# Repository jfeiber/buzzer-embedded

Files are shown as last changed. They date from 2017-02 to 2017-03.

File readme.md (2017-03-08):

# Buzzer-Embedded

The embedded code portion of the Buzzer project. For the web app portion/main README see: https://github.com/jfeiber/buzzer. 

## Architecture

The embedded portion of the Buzzer code is writtenly entirely in C++. Two external libraries are used: [SSD1306Ascii](https://github.com/greiman/SSD1306Ascii), a lightweight text-only library for interacting with the OLED screen, and [ArduinoJson](https://github.com/bblanchon/ArduinoJson), a lightweight stack-only library for encoding/decoding JSON. 

## Setup and Deployment

These instructions will get you a copy of the project up and running on your local machine for development purposes. To test you actually need a Buzzer and some cables. 

### Prerequisities

1. [Arduino IDE](https://www.arduino.cc/en/main/software)
2.  Once you have the Arduino IDE installed, install the two required libraries by going to `Sketch`->`Include Libraries`->`Manage Libraries` and search for the two required libraries and install them. [You can alternatively install them manually if that's more your game, although I don't see why you would.](https://www.arduino.cc/en/guide/libraries)

### Installing

1. Clone this repo
2. Open the `buzzer` folder of this repo in the Arduino IDE and compile. Everything should build properly. 

### General Repo Organization
* `/`
  * `/Box CAD Files/`: Contains all the Solidworks part, Solidworks assembly, and .stl files for the Buzzer container.
    * `buzzer_Top.*`: The top part of the Buzzer container.
    * `buzzer_bottom.*`: The bottom, main portion of the Buzzer where most of the components go in.
    * `buzzer.sldasm`: A Solidworks assembly file that shows how the two above parts are supposed to fit together.
  * `/PCB Design Files/`: Contains all the HTML templates used by the web app.
    * `buzzereater.fzz`: A [Fritzing](http://fritzing.org/home/) file for the PCB. Current rev is 2.
    * `/buzzer_gerber/`: Contains the [Gerber](https://en.wikipedia.org/wiki/Gerber_format) files for the Buzzer PCB. This is what's actually sent to the PCB manufacturer. 
  * `/buzzer/`: Contains the actual embedded code files.
  * `readme.md`: The READme you're currently reading.

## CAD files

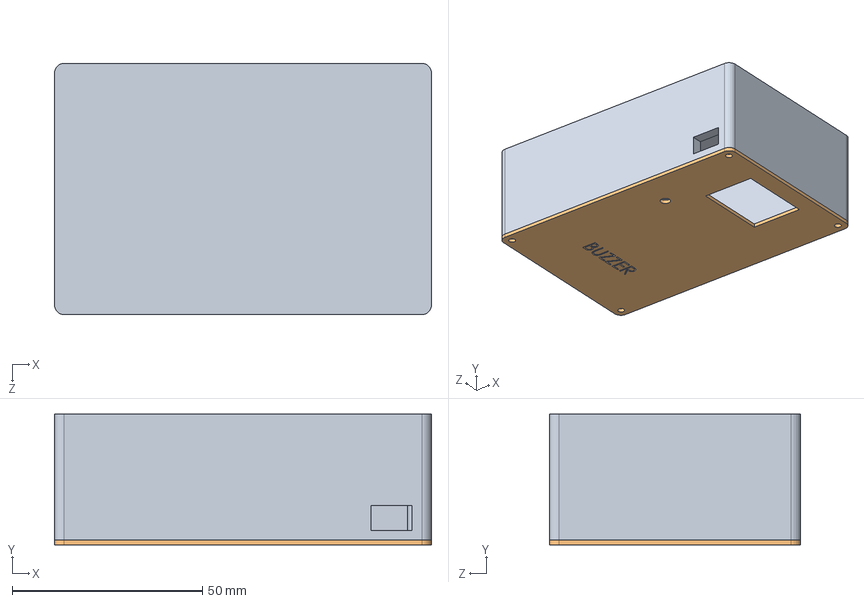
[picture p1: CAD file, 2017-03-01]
Box CAD Files/buzzer.sldasm
99.1 x 34.3 x 66.0 mm
buzzer_bottom
buzzer_Top

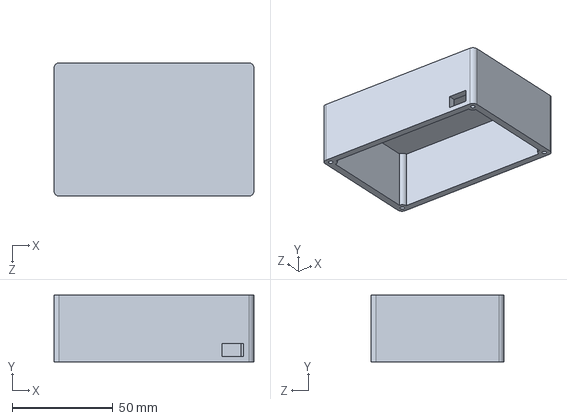
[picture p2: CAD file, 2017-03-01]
Box CAD Files/buzzer_bottom.sldprt
99.1 x 33.0 x 66.0 mm

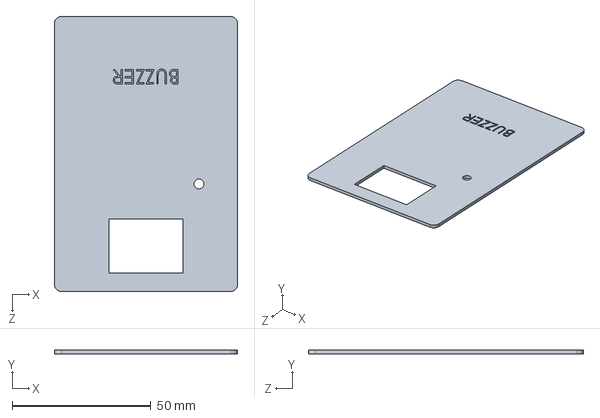
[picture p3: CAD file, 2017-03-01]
Box CAD Files/buzzer_Top.sldprt
66.0 x 1.27 x 99.1 mm

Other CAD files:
Box CAD Files/buzzer_Top.stl
Box CAD Files/buzzer_bottom.stl

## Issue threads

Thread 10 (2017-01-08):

There are 6 3D printed boxes that need things put in them

jfeiber, 2017-01-08:

jfeiber, 2017-02-19:
this took a lot longer than expected but all buzzers are finally assembled.

But i'm pretty sure 2 buzzers have bad cell modems so that's fun

Closed 2017-02-19.

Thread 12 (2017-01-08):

Buzzer doesn't show any indication that it's plugged in/charging

jfeiber, 2017-01-08:

Closed 2017-01-16.

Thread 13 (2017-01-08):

Buzzer should indicate battery level

jfeiber, 2017-01-08:

Closed 2017-01-16.

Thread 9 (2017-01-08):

Order parts to finish building out boxes

jfeiber, 2017-01-08:
Need to order more OLED screens

jfeiber, 2017-01-08:
Need more lipos

jfeiber, 2017-01-10:
OLED screens ordered.

jfeiber, 2017-01-10:
Ordered micro usb cables and material to put on lipos so I don't almost burn things down again

jfeiber, 2017-01-11:
Lipos on backorder

jfeiber, 2017-01-11:
Need more cell radios and antennas

jfeiber, 2017-01-20:
All parts should be on order.

Closed 2017-01-20.

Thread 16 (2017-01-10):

PCB Design Can Be More Effecient

jfeiber, 2017-01-10:
- Can get rid of 8 pins for OLED and just have 5. Should label them to make my life easier.
- Change button layout to only be 2 pins.
- Move button and vibration motor stuff down to make board smaller.

jfeiber, 2017-01-10:
The probable final PCB design has been mocked up. Waiting until I fully assemble a box with a PCB to make sure I don't need to make any other changes before I order.

jfeiber, 2017-01-20:
PCBs have been ordered.

Closed 2017-01-20.

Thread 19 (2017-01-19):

Buzzer not recognizing usb cable when plugged in via cable in box

jfeiber, 2017-01-19:

Closed 2017-01-20.

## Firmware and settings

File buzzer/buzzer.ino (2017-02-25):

/*
  File:
  buzzer.ino

  Description:
  The main file in this project. Includes the setup() and loop() methods. setup() is called by the
  Arduino on reset and loop is basically the main method of the program that's called repeatedly
  by the Arduino after setup() has finished.

*/

#include "Helpers.h"
#include "BuzzerFSMCallbacks.h"
#include "Globals.h"
#include "Pins.h"
#include "EEPROMReadWrite.h"
#include "LPF.h"
#include "Version.h"

// Initializations of global variables definied in "Globals.h".
BuzzerFSM buzzer_fsm({INIT_FONA, INIT, INIT, InitFunc}, INIT);
SoftwareSerial fona_serial = SoftwareSerial(FONA_TX_PIN, FONA_RX_PIN);
FonaShield fona_shield(&fona_serial, FONA_RST_PIN);
SSD1306AsciiAvrI2c oled;
// char eeprom_data.buzzer_name[30];
// int party_id = NO_PARTY;
EEPROMData eeprom_data;
short wait_time = NO_PARTY;
char party_name[20];
short batt_percentage = 100;
bool has_system_been_initialized = false;
unsigned long button_press_start = 0;
unsigned long last_batt_update = 0;
bool usb_cabled_plugged_in = false;

/*
 * Adds all states to the Buzzer FSM.
*/

void init_fsm() {
  buzzer_fsm.AddState({INIT_GPRS, INIT, INIT, InitFonaShieldFunc}, INIT_FONA);
  int init_gprs_next_state = CHECK_BUZZER_REGISTRATION;
  if (strlen(eeprom_data.buzzer_name) == 0 || eeprom_data.buzzer_name[0] == 0xFFFFFFFF) init_gprs_next_state = GET_BUZZER_NAME;
  int check_buzzer_reg_next_state = (eeprom_data.curr_party_id != NO_PARTY && eeprom_data.curr_party_id != 0) ? HEARTBEAT : IDLE;
  buzzer_fsm.AddState({init_gprs_next_state, INIT, INIT, InitGPRSFunc}, INIT_GPRS);
  buzzer_fsm.AddState({check_buzzer_reg_next_state, FATAL_ERROR, WAIT_BUZZER_REGISTRATION, CheckBuzzerRegFunc}, CHECK_BUZZER_REGISTRATION);
  buzzer_fsm.AddState({WAIT_BUZZER_REGISTRATION, FATAL_ERROR, FATAL_ERROR, GetBuzzerNameFunc}, GET_BUZZER_NAME);
  buzzer_fsm.AddState({GET_AVAILABLE_PARTY, FATAL_ERROR, FATAL_ERROR, IdleFunc}, IDLE);
  buzzer_fsm.AddState({IDLE, FATAL_ERROR, FATAL_ERROR, WaitBuzzerRegFunc}, WAIT_BUZZER_REGISTRATION);
  buzzer_fsm.AddState({ACCEPT_AVAILABLE_PARTY, FATAL_ERROR, IDLE, GetAvailPartyFunc}, GET_AVAILABLE_PARTY);
  buzzer_fsm.AddState({HEARTBEAT, FATAL_ERROR, IDLE, AcceptAvailPartyFunc}, ACCEPT_AVAILABLE_PARTY);
  buzzer_fsm.AddState({BUZZ, FATAL_ERROR, IDLE, HeartbeatFunc}, HEARTBEAT);
  buzzer_fsm.AddState({IDLE, FATAL_ERROR, BUZZ, BuzzFunc}, BUZZ);
  buzzer_fsm.AddState({IDLE, INIT, HEARTBEAT, WakeupFunc}, WAKEUP);
  buzzer_fsm.AddState({SLEEP, FATAL_ERROR, FATAL_ERROR, ShutdownFunc}, SHUTDOWN);
  buzzer_fsm.AddState({IDLE, FATAL_ERROR, FATAL_ERROR, SleepFunc}, SLEEP);
  buzzer_fsm.AddState({IDLE, FATAL_ERROR, FATAL_ERROR, ChargeFunc}, CHARGING);
  buzzer_fsm.AddState({INIT, INIT, INIT, FatalErrorFunc}, FATAL_ERROR);
  buzzer_fsm.AddState({HEARTBEAT, FATAL_ERROR, IDLE, LowCellReceptionFunc}, LOW_CELL_RECEPTION);
}

/*
 * The name of the Buzzer is stored in EEPROM. This function reads the bytes at the location
 * where the name should be stored (0x0) and stores it in a global variable.
*/

void get_buzzer_name_from_eeprom() {
  EEPROM.get(0, eeprom_data);
  DEBUG_PRINTLN_FLASH("Stored in eeprom: ");
  DEBUG_PRINTLN(eeprom_data.buzzer_name);
  DEBUG_PRINTLN(eeprom_data.curr_party_id);
}

/*
 * Buzzes the vibration motor twice. Used in the setup sequence to verify that the buzzer is
 * working.
*/

void buzz_twice() {
  analogWrite(BUZZER_PIN, 255);
  delay(300);
  analogWrite(BUZZER_PIN, 0);
  delay(300);
  analogWrite(BUZZER_PIN, 255);
  delay(300);
  analogWrite(BUZZER_PIN, 0);
}

/*
 * Sets up all the various peripheral pins.
*/

void setup_pins() {
  digitalWrite(ARDUINO_RST_PIN, HIGH);
  pinMode(LED_BUILTIN, OUTPUT);
  pinMode(FONA_RST_PIN, OUTPUT);
  pinMode(BUTTON_PIN, INPUT);
  pinMode(BUZZER_PIN, OUTPUT);
  pinMode(ARDUINO_RST_PIN, OUTPUT);
  #if BOARD_TYPE == V1 || BOARD_TYPE == V2
  // enable internal pull up resistor in arduino
  digitalWrite(BUTTON_PIN, HIGH);
  #endif
}

/*
  * Initializes the OLED screen.
*/

void init_oled() {
  oled.reset(OLED_RST);
  oled.begin(&Adafruit128x64, I2C_ADDRESS);
  oled.setFont(Adafruit5x7);
  // invert display?
  // oled.ssd1306WriteCmd(SSD1306_INVERTDISPLAY);
  oled.ssd1306WriteCmd(SSD1306_SEGREMAP);
  oled.ssd1306WriteCmd(SSD1306_COMSCANINC);
}

/*
 * Called on reset. Sets up the GPIO pins in the right modes, initializes the OLED, tests the
 * vibration motor, gets the buzzer name from the EEPROM (if there is one), and Initializes
 * the FSM.
*/

void setup() {
  Serial.begin(115200);
  // ClearEEPROM();
  setup_pins();
  init_oled();
  buzz_twice();
  get_buzzer_name_from_eeprom();
  if (eeprom_data.buzzer_name[0] == 0xFFFFFFFF) eeprom_data.curr_party_id = -1;
  init_fsm();
}

/*
 * The core method of Buzzer. After setup has completed, this method is called repeatedly in an
 * endless loop.
 *
 * This method processes the current FSM state and feeds the current battery voltage into a low
 * pass filter (to reduce noise) every 15 seconds. If something has happened with one of the
 * peripherals (USB cable plugged in, button pressed), this method will tell the FSM about that
 * event.
*/

void loop() {
  // Do the work of the current FSM state.
  buzzer_fsm.ProcessState();

  // Feed the current battery voltage (the battery voltage of the FONA lipo and the battery voltage
  // of the arduino lipo combined) into a LPF every 7.5 seconds.
  if (last_batt_update == 0 || millis() - last_batt_update >= 7500) {
    int fona_batt_voltage = fona_shield.GetBatteryVoltage();

    // If readVcc > 4.3V (4300mV), that means the USB cable is plugged in and we should read the
    // Arduino lipo voltage from A0. The -400 at the end is a fudge factor because the ADC on the
    // Arduino has an inherent bias. When the Arduino is running of the lipo the battery voltage
    // is just Vcc. We can't measure the lipo voltage accurately from A0 because the reference
    // voltage isn't constant when running of the battery (the battery is draining).
    int arduino_batt_voltage = (readVcc() >= 4300) ? ((analogRead(A0)/1023.0*5.0)*1000)-400 : readVcc();
    if (fona_batt_voltage != -1) {
      int total_batt_voltage = fona_batt_voltage + arduino_batt_voltage;
      int instantaneous_total_batt_voltage = ((total_batt_voltage-7400)/(float)(8400-7400))*100;
      if (get_curr_lpf_val() == 0) seed_lpf(instantaneous_total_batt_voltage);
      add_val_to_lpf(instantaneous_total_batt_voltage);
      batt_percentage = get_curr_lpf_val();
    }
    last_batt_update = millis();
  }

  // Poke the FSM if the the USB cable has been plugged in or unplugged.
  if (readVcc() >= 4300 && !usb_cabled_plugged_in) {
    usb_cabled_plugged_in = true;
    buzzer_fsm.USBCablePluggedIn();
  }
  if (readVcc() < 4300 && usb_cabled_plugged_in) {
    usb_cabled_plugged_in = false;
    buzzer_fsm.USBCableUnplugged();
  }

  // Poke the FSM if the cell reception gets low. Might not result in a state transition if the FSM
  // isn't in IDLE or HEARTBEAT
  int rssi_val = fona_shield.GetRSSIVal();
  if (rssi_val != -1 && rssi_val < LOW_SIGNAL_THRESHOLD) buzzer_fsm.LowCellReception();

  // Record the start time of a button press.
  if (digitalRead(BUTTON_PIN) == BUTTON_LOGIC_HIGH && button_press_start == 0) button_press_start = millis();

  // If a button press duration is longer than 5 seconds (5000 ms), poke the FSM.
  if (button_press_start != 0) {
    unsigned long button_press_duration = get_button_press_duration(button_press_start);
    if (button_press_duration >= 5000) {
      DEBUG_PRINTLN_FLASH("Long button press registered");
      buzzer_fsm.LongButtonPress();
      button_press_start = 0;
    }
  }

  // If it was a short button press and the button has now been released, poke the FSM.
  if (digitalRead(BUTTON_PIN) == BUTTON_LOGIC_LOW && button_press_start != 0) {
    unsigned long button_press_duration = get_button_press_duration(button_press_start);
    if (button_press_duration > 0 && button_press_duration < 5000) {
      DEBUG_PRINTLN_FLASH("Short button press registered.");
      buzzer_fsm.ShortButtonPress();
    }
    button_press_start = 0;
  }
}

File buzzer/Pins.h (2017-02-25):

/*
  File:
  Pins.h

  Description:
  Defines for the various peripheral pins.
 */

#ifndef PINS_H
#define PINS_H

#include "Version.h"


#if BOARD_TYPE == V2 || BOARD_TYPE == V1
  #define BUTTON_LOGIC_HIGH LOW
  #define BUTTON_LOGIC_LOW HIGH
#elif BOARD_TYPE == JANKBOARD
  #define BUTTON_LOGIC_HIGH HIGH
  #define BUTTON_LOGIC_LOW LOW
#endif

#define BUZZER_PIN 6
#define FONA_RX_PIN 12
#define FONA_TX_PIN 3

#if BOARD_TYPE == V2 || BOARD_TYPE == V1
  #define FONA_RST_PIN 13
#endif

#define BUTTON_PIN 8
#define ARDUINO_RST_PIN 10
// 0X3C+SA0 - 0x3C or 0x3D
#define I2C_ADDRESS 0x3D
#define OLED_RST 9

#endif

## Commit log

2016-10-08 Code to make things buzz
    [Pins.h, buzzer.ino]
2016-10-21 New methods for interacting with the EEPROM. Put Globals/Macros in their own files and made it so other things can access them. BuzzerFSM: added a return value for timeout. BuzzerFSMCallbacks: added 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
    [BuzzerFSMCallbacks.cpp]
2016-10-22 Added states/methods to deal with registering a buzzer.
    [BuzzerFSMCallbacks.cpp, buzzer.ino]
2016-10-22 added in a button
2016-10-22 working on the meat of the buzzer logic
    [BuzzerFSMCallbacks.cpp, buzzer.ino]
2016-10-23 Most of the core buzzer logic now works
    [BuzzerFSMCallbacks.cpp, buzzer.ino]
2016-10-31 Change pin for new 128x64 OLED display.
2016-11-05 More informative wait time display when the buzzer is in the heartbeat state.
    [BuzzerFSMCallbacks.cpp, buzzer.ino]
2016-11-13 Include whether or not the buzzer is currently buzzing in the heartbeat JSON obj for presentation diagnostics
    [BuzzerFSMCallbacks.cpp]
2017-01-09 Misc. Stuff, don't really remember what's in this right now. Probably PCB Gerber files and pin changes. Will go back later and figure it out
    [buzzereater.fzz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]
2017-01-10 Possible final PCB design. Changed OLED to only be 5 pins, moved vibration motor and button down.
    [buzzereater.fzz]
2017-01-11 Changes to PCB for measuring lipo voltages
    [buzzereater.fzz]
2017-01-13 Beginnings of reading battery voltage, got rid of a while loop in an FSM function.
2017-01-13 Can now shutdown/startup the buzzer
    [BuzzerFSMCallbacks.cpp, buzzer.ino]
2017-01-14 charging stuff mostly works but is v messy right now. Also the trinket is running out of RAM so that's a problem
    [BuzzerFSMCallbacks.cpp, buzzer.ino]
2017-01-15 A lot of the charging code now works but the memory issues are still there so that's going to be an adventure
    [BuzzerFSMCallbacks.cpp, buzzer.ino]
2017-01-15 New PCB Gerber file
    [buzzereater.fzz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]
2017-01-15 A bunch of cleanup and bug fixes
    [BuzzerFSMCallbacks.cpp]
2017-01-15 Fixed the screen flicker problem
    [BuzzerFSMCallbacks.cpp, buzzer.ino]
2017-01-15 Got rid of random screenshot
    [buzzereater.fzz]
2017-01-17 Some comments in BuzzerFSMCallbacks
    [BuzzerFSMCallbacks.cpp]
2017-01-20 Fixed the issue where the buzzer wasn't transitioning to the charge state when the USB cable was plugged into the box.
    [buzzer.ino]
2017-01-22 Added a dedicated state for if a fatal error occurs, cleaned up the error handling for a bunch of states.
    [BuzzerFSMCallbacks.cpp, buzzer.ino]
2017-01-23 Even better error handling
    [BuzzerFSMCallbacks.cpp, buzzer.ino]
2017-01-25 Buzzer now recovers from a crash if it was active. Changes to the EEPROM and more error handling stuff.
    [BuzzerFSMCallbacks.cpp, Pins.h, buzzer.ino]
2017-01-30 Fixed problem where a Buzzer with an active party would get shutdown and would wakeup and go to IDLE instead of HEARTBEAT
    [BuzzerFSMCallbacks.cpp, buzzer.ino]
2017-02-12 Fixes a problem where a FonaShield method wasn't properly erroring and the AcceptAvailPartyFunc would fatal error when it wasn't actually a fatal error
    [BuzzerFSMCallbacks.cpp, buzzer.ino]
2017-02-19 New FSM/FonaShield stuff to detect when the buzzer goes out of cell range
    [BuzzerFSMCallbacks.cpp, buzzer.ino]
2017-02-25 Fixes a longstanding buffer overflow error, fixes a problem with the cell modems (dangling reset pin), introduces conditional compilation for different PCB revs, gets rid of the estimated wait time d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
    [BuzzerFSMCallbacks.cpp, Pins.h]
2017-03-01 Reorganzing this repo a little bit, added in CAD files
    [buzzer.sldasm, buzzer_Top.sldprt, buzzer_Top.stl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]
